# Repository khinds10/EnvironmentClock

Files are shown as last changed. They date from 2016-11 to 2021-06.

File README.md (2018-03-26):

# EnvironmentClock - RPi Time/Weather Clock

#### Flashing RaspberriPi Hard Disk / Install Required Software (Using Ubuntu Linux)

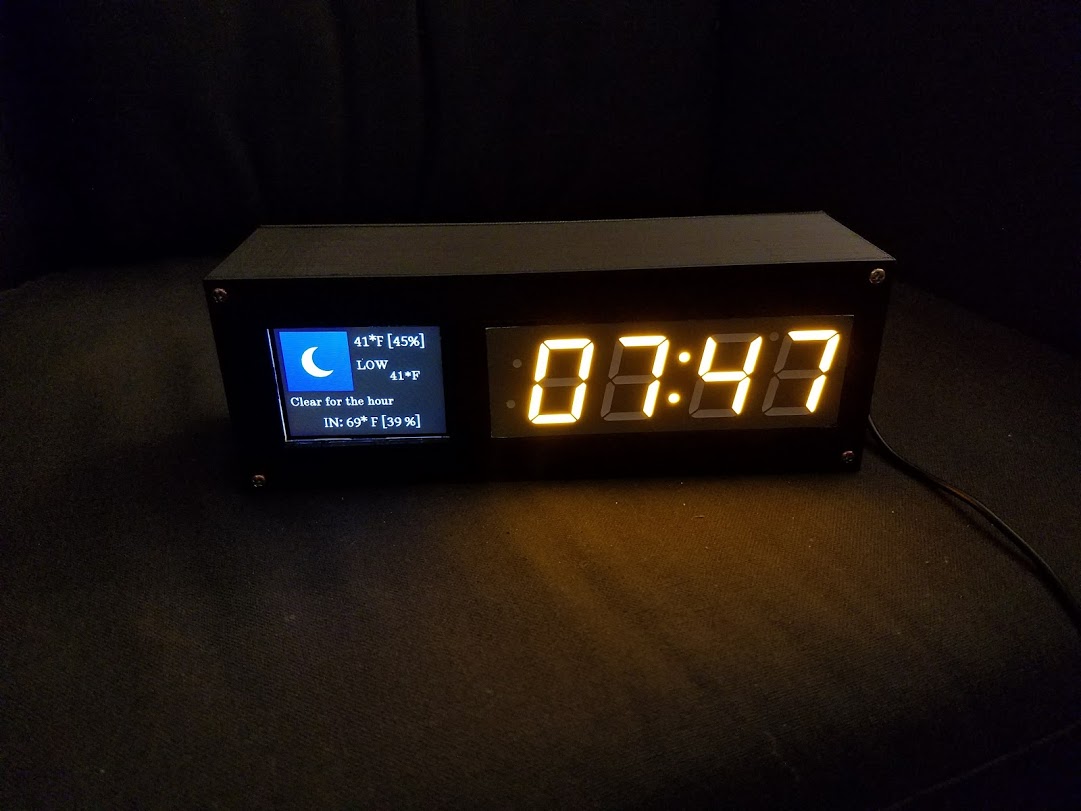
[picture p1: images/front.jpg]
EnvironmentClock


Download "RASPBIAN JESSIE LITE"
https://www.raspberrypi.org/downloads/raspbian/

**Create your new hard disk for DashboardPI**
>Insert the microSD to your computer via USB adapter and create the disk image using the `dd` command
>
> Locate your inserted microSD card via the `df -h` command, unmount it and create the disk image with the disk copy `dd` command
> 
> $ `df -h`
> */dev/sdb1       7.4G   32K  7.4G   1% /media/XXX/1234-5678*
> 
> $ `umount /dev/sdb1`
> 
> **Caution: be sure the command is completely accurate, you can damage other disks with this command**
> 
> *if=location of RASPBIAN JESSIE LITE image file*
> *of=location of your microSD card*
> 
> $ `sudo dd bs=4M if=/path/to/raspbian-jessie-lite.img of=/dev/sdb`
> *(note: in this case, it's /dev/sdb, /dev/sdb1 was an existing factory partition on the microSD)*

**Setting up your RaspberriPi**

*Insert your new microSD card to the raspberrypi and power it on with a monitor connected to the HDMI port*

Login
> user: **pi**
> pass: **raspberry**

Change your account password for security
>`sudo passwd pi`

Enable RaspberriPi Advanced Options
>`sudo raspi-config`

Choose:
`1 Expand File System`

`9 Advanced Options`
>`A2 Hostname`
>*change it to "EnvironmentClock"*
>
>`A4 SSH`
>*Enable SSH Server*
>
>`A7 I2C`
>*Enable i2c interface*

**Enable the English/US Keyboard**

>`sudo nano /etc/default/keyboard`

> Change the following line:
>`XKBLAYOUT="us"`

**Reboot PI for Keyboard layout changes / file system resizing to take effect**
>$ `sudo shutdown -r now`

**Auto-Connect to your WiFi**

>`sudo nano /etc/wpa_supplicant/wpa_supplicant.conf`

Add the following lines to have your raspberrypi automatically connect to your home WiFi
*(if your wireless network is named "linksys" for example, in the following example)*

	network={
	   ssid="linksys"
	   psk="WIRELESS PASSWORD HERE"
	}

**Reboot PI to connect to WiFi network**

>$ `sudo shutdown -r now`
>
>Now that your PI is finally on the local network, you can login remotely to it via SSH.
>But first you need to get the IP address it currently has.
>
>$ `ifconfig`
>*Look for "inet addr: 192.168.XXX.XXX" in the following command's output for your PI's IP Address*

**Go to another machine and login to your raspberrypi via ssh**

> $ `ssh pi@192.168.XXX.XXX`

**Start Installing required packages**

>$ `sudo apt-get update`
>
>$ `sudo apt-get upgrade`
>
>$ `sudo apt-get install vim git python-requests python-smbus i2c-tools python-imaging python-smbus build-essential python-dev rpi.gpio python3 python3-pip libi2c-dev`

**Update local timezone settings**

>$ `sudo dpkg-reconfigure tzdata`

> select your timezone using the interface

**Setup the simple directory `l` command [optional]**

>$ `vi ~/.bashrc`
>
>*add the following line:*
>
>$ `alias l='ls -lh'`
>
>$ `source ~/.bashrc`

**Fix VIM default syntax highlighting [optional]**

>$ `sudo vi /etc/vim/vimrc`
>
>uncomment the following line:
>
>_syntax on_

**Clone Clock repository**

>$ `cd ~`
>
>$ `git clone https://github.com/khinds10/EnvironmentClock.git`

**Install i2c Backpack Python Drivers**

>$ `cd ~`
>
>$ `git clone https://github.com/adafruit/Adafruit_Python_LED_Backpack`
>
>$ `cd Adafruit_Python_LED_Backpack/`
>
>$ `sudo python setup.py install`
>

**DHT11 Install**

>$ `cd ~`
>
>$ `git clone https://github.com/adafruit/Adafruit_Python_DHT.git`
>
>$ `cd Adafruit_Python_DHT/`
>
>$ `sudo python setup.py install`
>
>$ `sudo python ez_setup.py`
>
>$ `cd examples/`
>
>$ `vi simpletest.py`
>

Change the following line:
> sensor = Adafruit_DHT.DHT11

Comment the line out
> pin = 'P8_11'

Uncomment the line and change the pin number to 16
> pin = 16

Run the test

`python simpletest.py`

> You should see a metric reading of Temp and Humidity displayed on the command line.

## Supplies Needed

**1.2 inch LED Display**

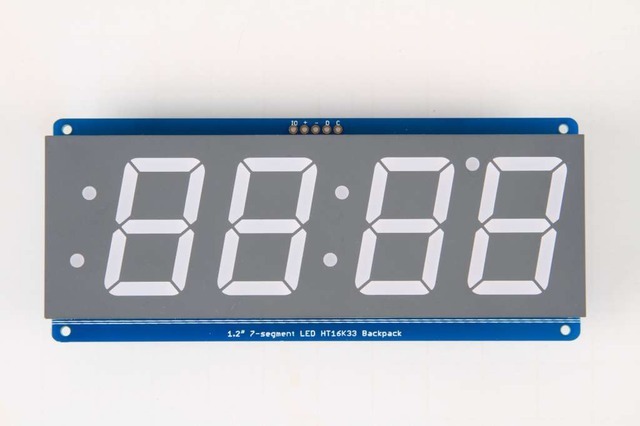
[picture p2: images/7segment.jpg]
1.2 inch LED Display


**DHT11 Humidistat**

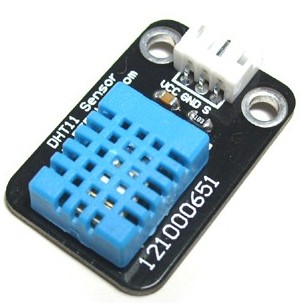
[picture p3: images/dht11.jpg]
DHT11 Humidistat


**2.6" Digole Display**

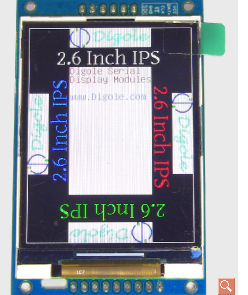
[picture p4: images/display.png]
Digole Display


**RaspberriPi Zero (or Regular RaspberriPi should work)**

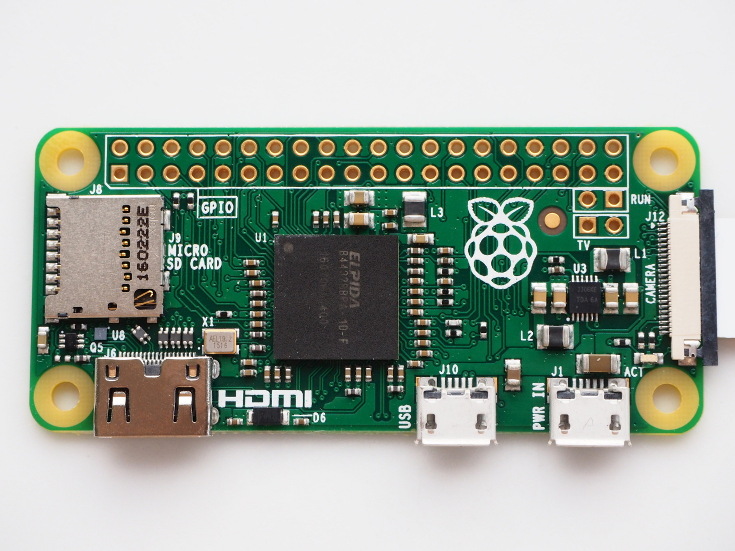
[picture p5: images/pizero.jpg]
Pi Zero


## Build and wire the device

**1) Prepare the Digole Display for i2C**

On the back of the Digole Display, solder the jumper to assign the display to use the i2c protocol
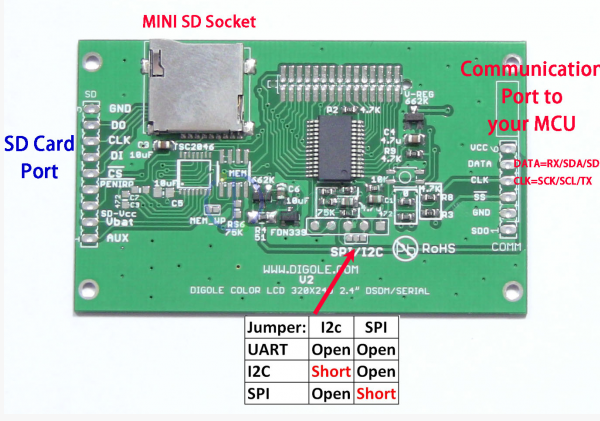
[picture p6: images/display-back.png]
i2c Jumper Digole


**2) Print the Project Enclosure**

Using a 3D printer print the enclosure files included in the 'enclosure/' folder.
.x3g files are MakerBot compatible.  You can also use the .stl and .blend (Blender Program) files to edit and create your own improvements to the design.

**3) Using 4 screws drill and attach the front panel (with the 2 holes) to the 4 sided body.  Then fit the displays in each of the holes.**

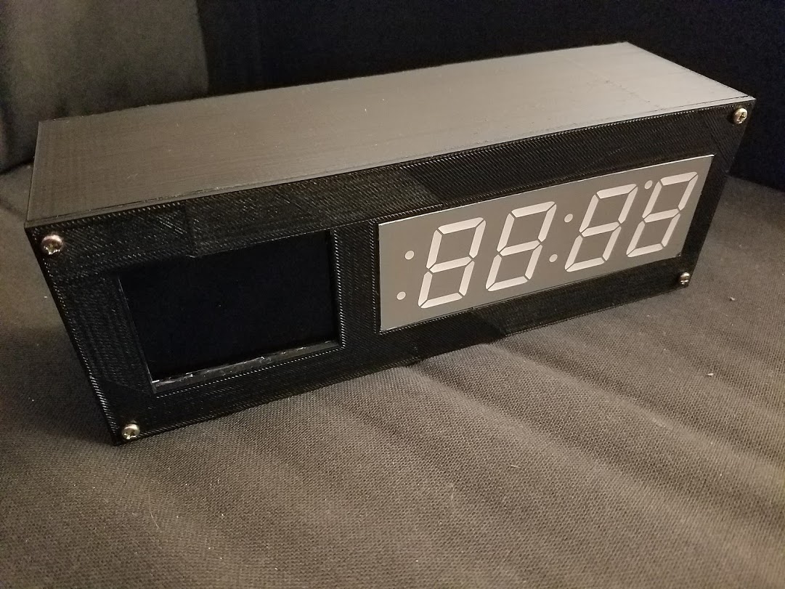
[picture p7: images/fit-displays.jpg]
Fit Displays


**4) Attach the 7 segment and Digole Display using hot glue gun to hold them in place.**

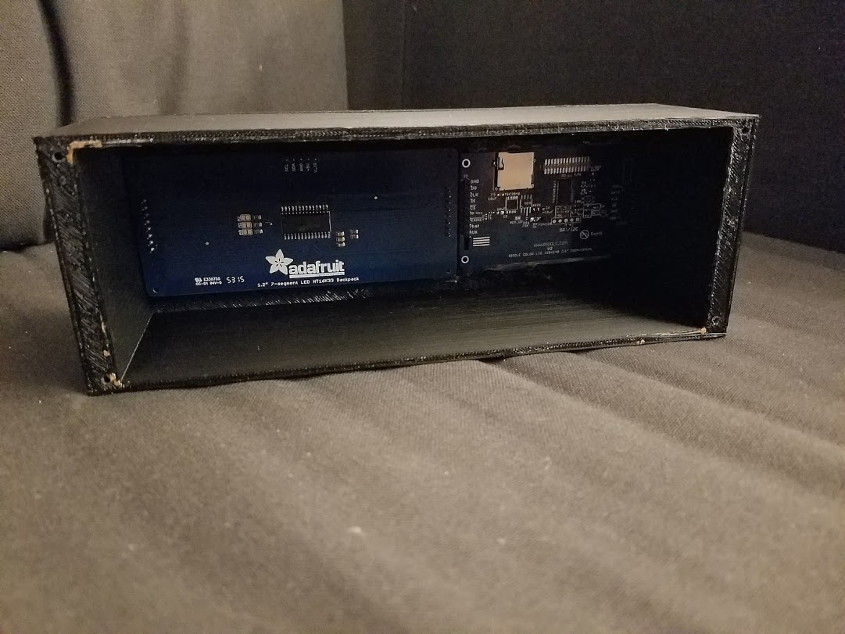
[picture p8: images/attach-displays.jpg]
Hot Glue Displays


**5) Prepare the wires for connection. I use standard jumping wires and a wire cutter to strip the wire bare in the middle of the wires so I can have a bunch connected together glued with a hot glue gun.  (In the image below is my grouped together 5V / GND / SCA / and SCL wires.)**

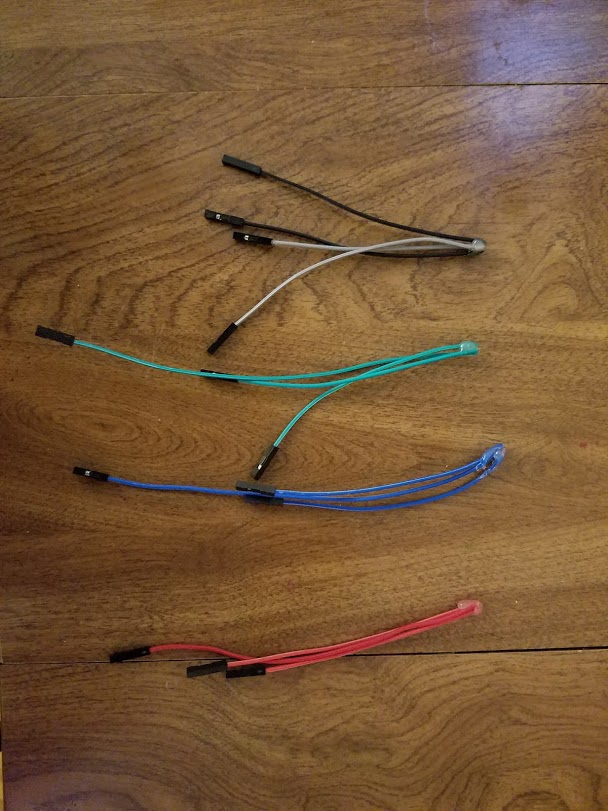
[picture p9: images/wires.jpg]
Grouped Wires


**6) Begin wiring the unit using the wiring diagram below as a guide.**

**The 7 Segment display**

> D -> SDA
>
> C -> SCL
>
> \+ -> 5v
>
> GND -> GND
>
> IO -> 5v
    
**Digole Display**

> GND -> GND
>
> DATA -> SDA
>
> CLK -> SCL
>
> VCC -> 3V
    
**DHT11 Humidistat**

> VCC -> 5V
>
> GND -> GND
>
> DATA -> GPIO 16 / PIN 36
>
    
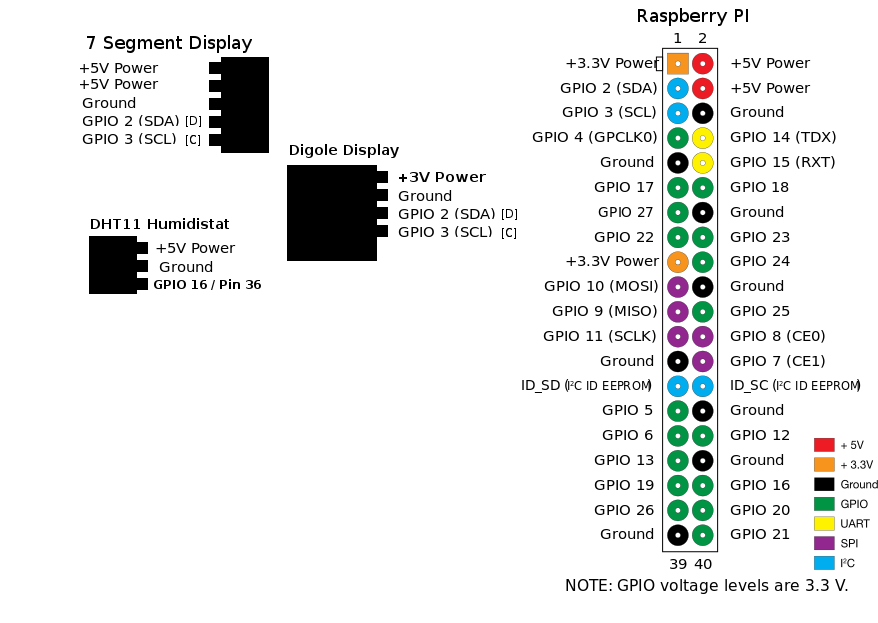
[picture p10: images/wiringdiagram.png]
Wiring Diagram


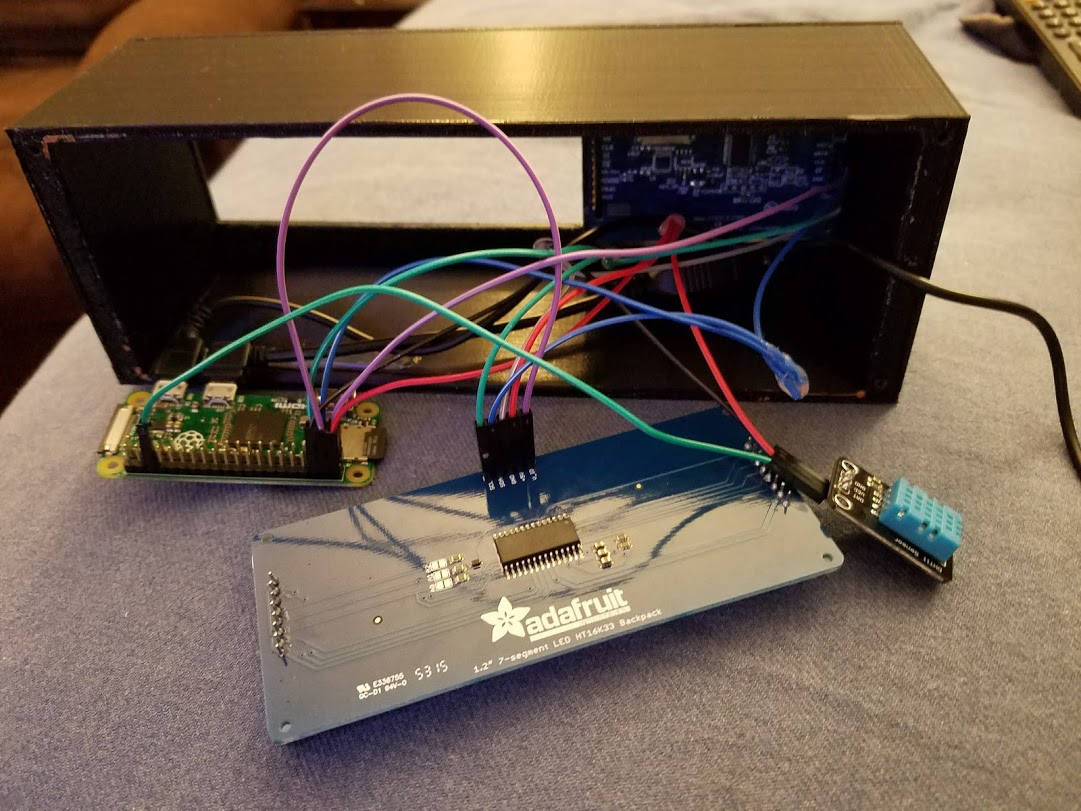
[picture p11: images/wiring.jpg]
Wiring Displays


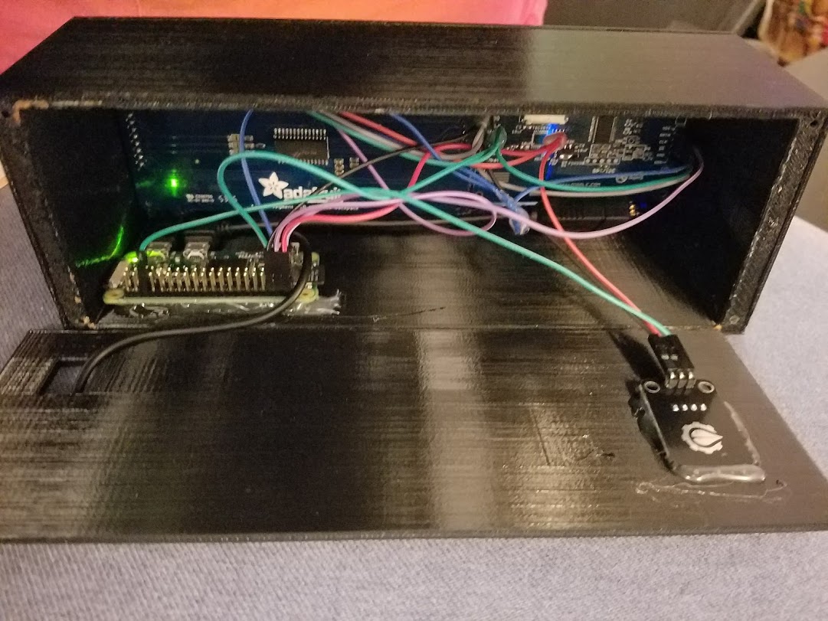
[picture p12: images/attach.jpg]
Attach Wired Displays


**7) Glue the humidistat to the back panel, and run a USB cable through the other back panel hole to power the unit.  Attach the back with only 2 screws in case you need to disassemble for repair.**

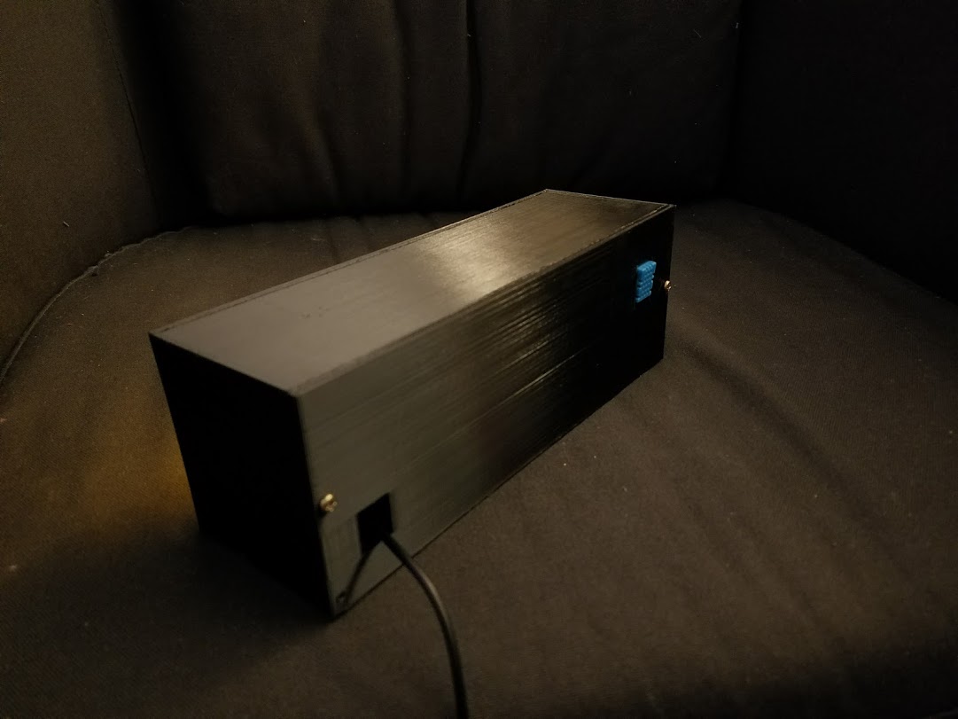
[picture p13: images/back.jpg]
Attach Back Panel


## Configure Application to run correctly in settings.py config file

Find the file `settings.py` and adjust to your current settings

> \# forecast.io API key for local weather information
>
> weatherAPIURL = 'https://api.forecast.io/forecast/'
>
> weatherAPIKey = 'YOUR API KEY FOR FORECAST.IO'
> 
> \# optional for running the remote temp/humidity logger
>
> deviceLoggerAPI = 'mydevicelogger.com'
>
> \# search google to get the Latitude/Longitude for your home location
>
> latitude = 41.4552578
>
> longitude = -72.1665444
>

## Setup Startup Scripts

>$ `crontab -e`

Add the following lines:

`@reboot nohup python /home/pi/EnvironmentClock/clock.py >/dev/null 2>&1`

`@reboot nohup python /home/pi/EnvironmentClock/display.py >/dev/null 2>&1`

Verify the display starts working on reboot

>$ `sudo reboot`

## OPTIONAL: Temp Logger to API script each 10 minutes

>$ `crontab -e`

Add the following lines:

`*/10 * * * * python /home/pi/EnvironmentClock/temp-check.py`

## OPTIONAL: Creating your own weather images to render on the display

Upload your own 128x128 file to the following URL:

http://www.digole.com/tools/PicturetoC_Hex_converter.php 

Choose your image file to upload, add what size you want it to be on the screen (Width/Height)

Select "256 Color for Color OLED/LCD(1 byte/pixel)" in the "Used for" dropdown

Obtain the hex output.

Add the hex output to a display/build/ header (.h) file, use the other ones as guides for syntax.

Include the new file in the digole.c file 
`#include "myimage.h`

Include a new command line hook to your image file in the.
_Note: the command below is saying draw your image at position 10 pixels over 10  pixels down. You can change it to different X,Y coordinates, you can also change the values 128,128 to whatever size your new image actually is._

`} else if (strcmp(digoleCommand, "myimage") == 0) {`
    `drawBitmap256(10, 10, 128, 128, &myimageVariableHere,0);  // myimageVariableHere is defined in your (.h) file`
`}`

Now rebuild (ignore the errors) below to have your new image render with the following command.
>$ `./digole myimage`

**Re-Building [Included] Digole Display Driver for your optional changes**

>$ `cd display/build`

>$ `gcc digole.c`

>$ `mv a.out ../../digole`

>$ `chmod +x ../../digole`

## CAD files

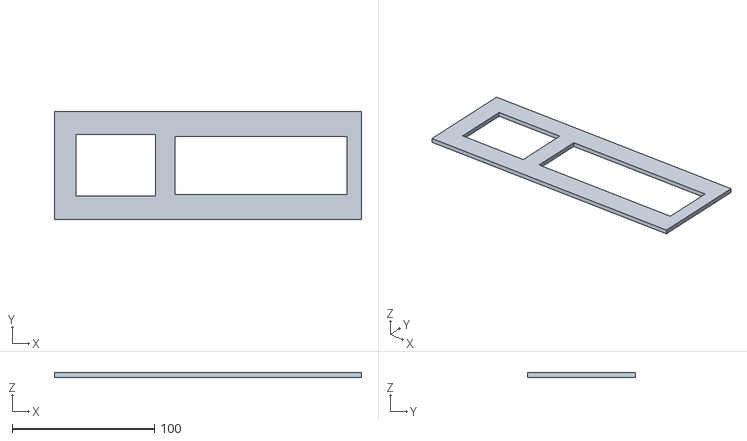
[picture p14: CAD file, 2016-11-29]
enclosure/EnvironmentClock-Lid.stl
215.9 x 76.2 x 3.18

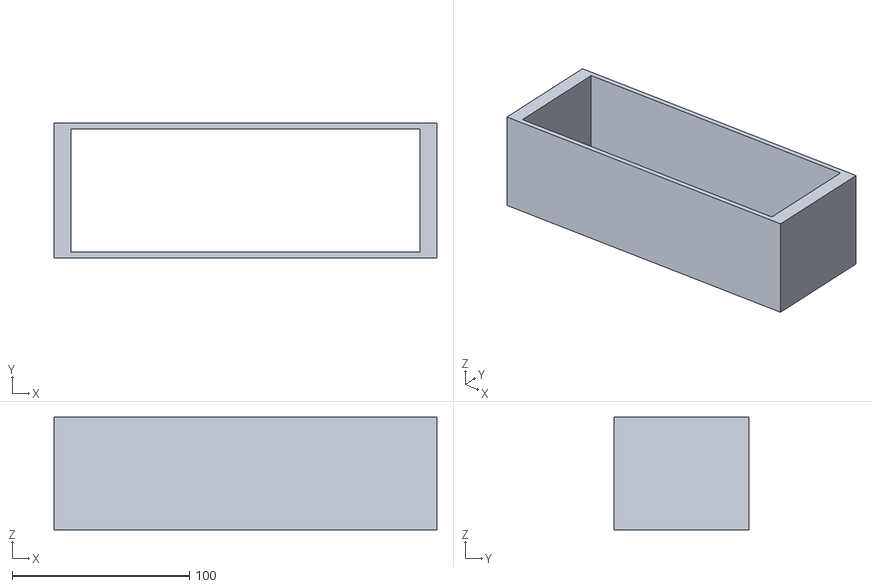
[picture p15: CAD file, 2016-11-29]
enclosure/EnvironmentClock-Box.stl
215.9 x 76.2 x 63.5

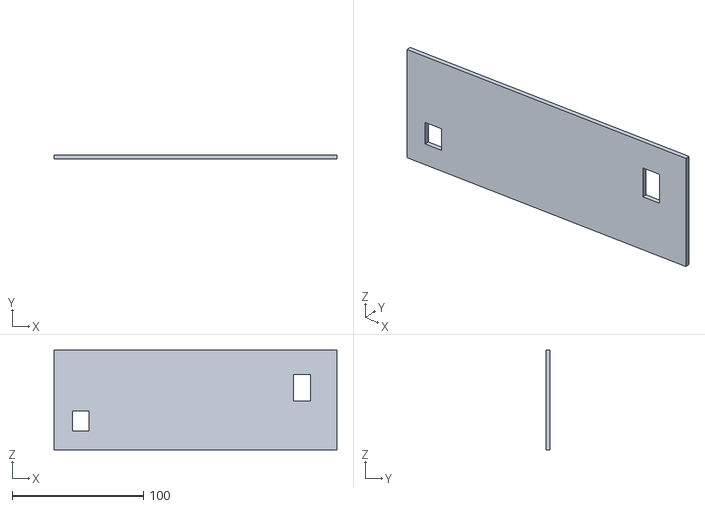
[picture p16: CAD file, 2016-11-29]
enclosure/EnvironmentClock-Back.stl
215.9 x 3.18 x 76.2

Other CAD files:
enclosure/EnvironmentClock-Back.blend
enclosure/EnvironmentClock-Box.blend
enclosure/EnvironmentClock-Lid-scratch.blend
enclosure/EnvironmentClock-Lid.blend

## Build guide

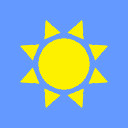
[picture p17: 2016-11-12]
display/build/images/clear-day.jpg

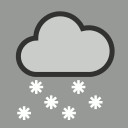
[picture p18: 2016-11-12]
display/build/images/snow.jpg

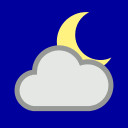
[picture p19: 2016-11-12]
display/build/images/partly-cloudy-night.jpg

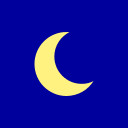
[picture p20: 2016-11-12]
display/build/images/clear-night.jpg

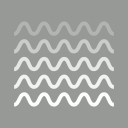
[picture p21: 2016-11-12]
display/build/images/fog.jpg

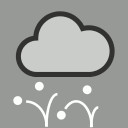
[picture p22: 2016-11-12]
display/build/images/sleet.jpg

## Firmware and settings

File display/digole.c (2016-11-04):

/////////////////////////////////
// Digole Digital
/////////////////////////////////
#include <arpa/inet.h>
#include <dirent.h>
#include <errno.h>
#include <net/if.h>
#include <netinet/in.h>
#include <netinet/in.h>
#include <pthread.h>
#include <stdint.h>
#include <stdio.h>
#include <stdlib.h>
#include <string.h>
#include <stropts.h>
#include <sys/ioctl.h>
#include <sys/socket.h>
#include <sys/types.h>
#include <sys/time.h>
#include <time.h>
#include <unistd.h>
#include <inttypes.h>
#include <linux/i2c-dev.h>
#include <fcntl.h>
#include <sys/ioctl.h>
#include <sys/stat.h>

#define _TEXT_ 0
#define _GRAPH_ 1
#define _rs 0
#define _rst 2
#define LCDWIDTH 128
#define LCDHEIGHT 64

// an abs() :)
#define abs(a) (((a) < 0) ? -(a) : (a))

// bit set
#define _BV(bit) (0x1 << (bit))
#define swap(a, b) { uint8_t t = a; a = b; b = t; }

int fd,fd2;
const unsigned char fonts[] = {6, 10, 18, 51, 120, 123};

// name of the port we will be using, Rasberry Pi model B (i2c-1)
char *fileName = "/dev/i2c-1";

// address of I2C device Digole
int  address = 0x27;

void delay (unsigned int howLong){
  struct timespec sleeper, dummy ;
  sleeper.tv_sec  = (time_t)(howLong / 1000) ;
  sleeper.tv_nsec = (long)(howLong % 1000) * 1000000 ;
  nanosleep (&sleeper, &dummy) ;
}
 int writebyte (uint8_t command) {
	    if( i2c_smbus_write_byte( fd, command ) < 0 ) {
            printf(" Error writing to i2c slave ");
			return -1;
        }
		return 0;
 }
 int writecmd(char *command) {
		char tmp[1000];
		int i;
		sprintf(tmp,"%s",command);
        printf(" Digole CMD: %s ",command);
		for (i=0;i<strlen(tmp);i++) {
			printf("%c",tmp[i]);
		    if ((writebyte(tmp[i]))==-1) {
				printf(" Error writing to i2c slave ");
				return -1;
			}
		}
		return 0;
 }
void setRot90(void) {
    writecmd("SD1");
}
void setRot180(void) {
    writecmd("SD2");
}
void setRot270(void) {
    writecmd("SD3");
}
void undoRotation(void) {
    writecmd("SD0");
}
void setRotation(uint8_t d) {
    writecmd("SD");
    writebyte(d);
}
void setContrast(uint8_t c) {
    writecmd("CT");
    writebyte(c);
}
int print(char *command) {
    char tmp[1000];
    writecmd("TT");
    writecmd(command);
    writebyte(0);
    return 0;
}
void displayStartScreen(uint8_t c) {
    writecmd("DSS");
    writebyte(c);
}
void drawBox(uint8_t x, uint8_t y, uint8_t w, uint8_t h) {
    writecmd("FR");
    writebyte(x);
    writebyte(y);
    writebyte(x + w);
    writebyte(y + h);
}
void drawFrame(uint8_t x, uint8_t y, uint8_t w, uint8_t h) {
    writecmd("DR");
    writebyte(x);
    writebyte(y);
    writebyte(x + w);
    writebyte(y + h);
}
void setColor(uint8_t color) {
    writecmd("SC");
    writebyte(color);
}
void drawBoxfill(uint8_t x, uint8_t y, uint8_t w, uint8_t h) {
	setColor(0);
	drawBox(x, y, w,h);
	setColor(1);
	drawFrame(x, y, w,h);
}
void clearobd() {
	setColor(0);
	drawBox(0, 0, 128,57);
	setColor(1);
}
void drawCircle(uint8_t x, uint8_t y, uint8_t r, uint8_t f) {
    writecmd("CC");
    writebyte(x);
    writebyte(y);
    writebyte(r);
    writebyte(f);
}
void drawDisc(uint8_t x, uint8_t y, uint8_t r) {
    drawCircle(x, y, r, 1);
}
void drawPixel(uint8_t x, uint8_t y, uint8_t color) {
    writecmd("DP");
    writebyte(x);
    writebyte(y);
    writebyte(color);
}
void drawLine(uint8_t x, uint8_t y, uint8_t x1, uint8_t y1) {
    writecmd("LN");
    writebyte(x);
    writebyte(y);
    writebyte(x1);
    writebyte(y1);
}
void drawLineTo(uint8_t x, uint8_t y) {
    writecmd("LT");
    writebyte(x);
    writebyte(y);
}
void drawHLine(uint8_t x, uint8_t y, uint8_t w) {
    drawLine(x, y, x + w, y);
}
void drawVLine(uint8_t x, uint8_t y, uint8_t h) {
    drawLine(x, y, x, y + h);
}
void nextTextLine(void) {
    writebyte((uint8_t) 0);
    writecmd("TRT");
}
void setFont(uint8_t font) {
    writecmd("SF");
    writebyte(font);
}
void directCommand(uint8_t d) {
    writecmd("MCD");
    writebyte(d);
}
void directData(uint8_t d) {
    writecmd("MDT");
    writebyte(d);
}
void moveArea(uint8_t x0, uint8_t y0, uint8_t x1, uint8_t y1, char xoffset, char yoffset) {
    writecmd("MA");
    writebyte(x0);
    writebyte(y0);
    writebyte(x1);
    writebyte(y1);
    writebyte(xoffset);
    writebyte(yoffset);
}
void uploadStartScreen(int lon,  uint8_t *data,int xdelay) {
     int j,y;
     uint8_t c;
    writecmd("SSS");
    writebyte((uint8_t) (lon % 256));
    writebyte((uint8_t) (lon / 256));
    for (j = 0; j < lon;j++) {
        delay(xdelay);
        c=*(data+j);
        writebyte(c);
		printf(" 0x%.2X ",c);
		if ((j%16)==0) printf(" ");
    }
}
void uploadUserFont(int lon, uint8_t *data, uint8_t sect) {
     uint8_t c;
	 int j;
    writecmd("SUF");
    writebyte(sect);
    writebyte((uint8_t) (lon % 256));
    writebyte((uint8_t) (lon / 256));
    for ( j = 0; j < lon; j++) {
        if((j%32)==0) delay(10);
        delay(2);
        c=*(data+j);
        writebyte(c);
    }
}
void clearScreen(void) {
        writebyte('C');
		writebyte('L');
		writebyte(0);
		writebyte('C');
		writebyte('L');
		writebyte(0);
}
//set display mode
void setMode(uint8_t m) {
        writecmd("DM");
        writebyte(m);
}
//set text position back to previous, only one back allowed
void setTextPosBack(void) {
	writecmd("ETB");
}
void setTextPosOffset(char xoffset, char yoffset) {
	writecmd("ETO");
	writebyte(xoffset);
	writebyte(yoffset);
}
void setTextPosAbs(uint8_t x, uint8_t y) {
	writecmd("ETP");
	writebyte(x);
	writebyte(y);
}
void setLinePattern(uint8_t pattern) {
	writecmd("SLP");
	writebyte(pattern);
 }
void setPrintPos(uint8_t x, uint8_t y, uint8_t graph ) {
        if (graph == _TEXT_)
            writecmd("TP");
		else
            writecmd("GP");
         writebyte(x);
         writebyte(y);
}
void disableCursor(void) {
    writecmd("CS0");
}
void enableCursor(void) {
    writecmd("CS1");
}
void drawStr(uint8_t x, uint8_t y, char *s) {
		setTextPosOffset(x,y);
		print(s);
}
/*----------Functions for Graphic LCD/OLED adapters only---------*/
void drawBitmap(uint8_t x, uint8_t y, uint8_t w, uint8_t h, const uint8_t *bitmap) {
    uint8_t i = 0;
	int j;
    if ((w & 7) != 0)
        i = 1;
    writecmd("DIM");
    writebyte(x); //x;
    writebyte(y);
    writebyte(w);
    writebyte(h);
    for ( j = 0; j < h * ((w >> 3) + i); j++) {
        writebyte(*(bitmap + j));
    }
}
void drawBitmapc(uint8_t x, uint8_t y, uint8_t w, uint8_t h, const uint8_t *bitmap,uint8_t c ) {
    uint8_t i = 0;
	int j;
	if (c!=0) c=0xff;
    if ((w & 7) != 0)
        i = 1;
    writecmd("DIM");
    writebyte(x);
    writebyte(y);
    writebyte(w);
    writebyte(h);
    for ( j = 0; j < h * ((w >> 3) + i); j++) {
        writebyte((*(bitmap + j))^c);
    }
}
const char *byte_to_binary(int x) {
    static char b[9];
    b[0] = '\0';
    int z;
    for (z = 128; z > 0; z >>= 1){
        strcat(b, ((x & z) == z) ? "1" : "0");
    }
    return b;
}
 int printxy(uint8_t x, uint8_t y, char *command) {
	setPrintPos(x, y,_TEXT_);
	writecmd("TT");
	writecmd(command);
	writebyte(0);
	return 0;
 }
 int printxy_abs(uint8_t x, uint8_t y, char *command) {
	setTextPosAbs(x, y);
	writecmd("TT");
	writecmd(command);
	writebyte(0);
	return 0;
 }
 int printxyf_abs(uint8_t x, uint8_t y,uint8_t font, char *command) {
	setFont(fonts[font]);
	setTextPosAbs(x, y);
	writecmd("TT");
	writecmd(command);
	writebyte(0);
	return 0;
 }
int printxyf(uint8_t x, uint8_t y,uint8_t font, char *command) {
	setFont(fonts[font]);
	setPrintPos(x, y,_TEXT_);
	writecmd("TT");
	writecmd(command);
	writebyte(0);
	return 0;
 }
int printnxyf(uint8_t x, uint8_t y,uint8_t font, int command) {
    char tmp[100];
    sprintf(tmp,"%d",command);
    setFont(fonts[font]);
    setPrintPos(x, y,_TEXT_);
    writecmd("TT");
    writecmd(tmp);
    writebyte(0);
    return 0;
 }
 int printnxyf_abs(uint8_t x, uint8_t y,uint8_t font, int command) {
    char tmp[100];
    sprintf(tmp,"%d",command);
    setFont(fonts[font]);
    setTextPosAbs(x, y);
    writecmd("TT");
    writecmd(tmp);
    writebyte(0);
    return 0;
 }
int LCDInit( uint8_t contrast) {
    // Open port for reading and writing
    if ((fd = open (fileName, O_RDWR)) < 0) {
        printf(" Failed to open i2c port ");
        return -1;
    }
    // Set the port options and set the address of the device
    if (ioctl(fd, I2C_SLAVE, address) < 0) {
        printf(" Unable to get bus access to talk to slave ");
        return -1;
    }
	return (0);
}
void LCDdrawbitmap(uint8_t x, uint8_t y, uint8_t *bitmap, uint8_t w, uint8_t h,uint8_t color,uint8_t *dest) {
uint8_t j,i,jj;
uint8_t o,p,k;
printf(" 000 0b ");
k=0;
for (p=0;p<(w/8);p++)
  for (o=0;o<=7;o++) {
		for ( j=0; j<h; j++) {
			for ( i=0; i<(w/8); i++ ) {
				uint8_t d = *(bitmap + i + (j)*w/8);
				for (jj = 8; jj>0; jj--)	{
					if (((jj-1)==(7-o)) && (i==p)) {
						if (d & _BV(jj-1))
						  printf("1");
						else
						  printf("0");
						k++;
						if (k%8==0)
							printf(",0b");
					 }
				}
			}
		}
		k=0;
		printf(" %.03d 0b ",(p*8)+o);
	}
}

int main (int argc, char* argv[]) {
    int i=0;
	LCDInit(0);
    printf(" %s ", argv[0]);

    // show incoming commands   
    printf(" arg%d=%s ", 1, argv[1]);
    printf(" arg%d=%s ", 2, argv[2]);

    // parse command to char
    char digoleCommand[100];
    sprintf(digoleCommand,"%s",argv[1]);
    
    // based on command issue call to Digole screen
    if (strcmp(digoleCommand, "setRot90") == 0) {
        setRot90();
    } else if (strcmp(digoleCommand, "setRot180") == 0) {
        setRot180();
    } else if (strcmp(digoleCommand, "setRot270") == 0) {
        setRot270();
    } else if (strcmp(digoleCommand, "undoRotation") == 0) {
        undoRotation();
    } else if (strcmp(digoleCommand, "setRotation") == 0) {
        setRotation((uint8_t)atoi(argv[2]));
    } else if (strcmp(digoleCommand, "setContrast") == 0) {
        setContrast((uint8_t)atoi(argv[2]));
    } else if (strcmp(digoleCommand, "displayStartScreen") == 0) {
        displayStartScreen((uint8_t)atoi(argv[2]));
    } else if (strcmp(digoleCommand, "drawBox") == 0) {
        drawBox((uint8_t)atoi(argv[2]), (uint8_t)atoi(argv[3]), (uint8_t)atoi(argv[4]), (uint8_t)atoi(argv[5]));
    } else if (strcmp(digoleCommand, "drawFrame") == 0) {
        drawFrame((uint8_t)atoi(argv[2]), (uint8_t)atoi(argv[3]), (uint8_t)atoi(argv[4]), (uint8_t)atoi(argv[5]));
    } else if (strcmp(digoleCommand, "setColor") == 0) {
        setColor((uint8_t)atoi(argv[2]));
    } else if (strcmp(digoleCommand, "drawBoxfill") == 0) {
        drawBoxfill((uint8_t)atoi(argv[2]), (uint8_t)atoi(argv[3]), (uint8_t)atoi(argv[4]), (uint8_t)atoi(argv[5]));
    } else if (strcmp(digoleCommand, "clearobd") == 0) {
        clearobd();
    } else if (strcmp(digoleCommand, "drawCircle") == 0) {
        drawCircle((uint8_t)atoi(argv[2]), (uint8_t)atoi(argv[3]), (uint8_t)atoi(argv[4]), (uint8_t)atoi(argv[5]));
    } else if (strcmp(digoleCommand, "drawDisc") == 0) {
        drawDisc((uint8_t)atoi(argv[2]), (uint8_t)atoi(argv[3]), (uint8_t)atoi(argv[4]));
    } else if (strcmp(digoleCommand, "drawPixel") == 0) {
        drawPixel((uint8_t)atoi(argv[2]), (uint8_t)atoi(argv[3]), (uint8_t)atoi(argv[4]));
    } else if (strcmp(digoleCommand, "drawLine") == 0) {
        drawLine((uint8_t)atoi(argv[2]), (uint8_t)atoi(argv[3]), (uint8_t)atoi(argv[4]), (uint8_t)atoi(argv[5]));
    } else if (strcmp(digoleCommand, "drawLineTo") == 0) {
        drawLineTo((uint8_t)atoi(argv[2]), (uint8_t)atoi(argv[3]));
    } else if (strcmp(digoleCommand, "drawHLine") == 0) {
        drawHLine((uint8_t)atoi(argv[2]), (uint8_t)atoi(argv[3]), (uint8_t)atoi(argv[4]));
    } else if (strcmp(digoleCommand, "drawVLine") == 0) {
        drawVLine((uint8_t)atoi(argv[2]), (uint8_t)atoi(argv[3]), (uint8_t)atoi(argv[4]));
    } else if (strcmp(digoleCommand, "nextTextLine") == 0) {
        nextTextLine();
    } else if (strcmp(digoleCommand, "setFont") == 0) {
        setFont((uint8_t)atoi(argv[2]));
    } else if (strcmp(digoleCommand, "directCommand") == 0) {
        directCommand((uint8_t)atoi(argv[2]));
    } else if (strcmp(digoleCommand, "directData") == 0) {
        directData((uint8_t)atoi(argv[2]));
    } else if (strcmp(digoleCommand, "moveArea") == 0) {
        moveArea((uint8_t)atoi(argv[2]), (uint8_t)atoi(argv[3]), (uint8_t)atoi(argv[4]), (uint8_t)atoi(argv[5]), (uint8_t)atoi(argv[6]), (uint8_t)atoi(argv[7]));
    } else if (strcmp(digoleCommand, "uploadStartScreen") == 0) {
        //uploadStartScreen(int lon,  uint8_t *data,int xdelay);
    } else if (strcmp(digoleCommand, "uploadUserFont") == 0) {
        //uploadUserFont(int lon, uint8_t *data, uint8_t sect);
    } else if (strcmp(digoleCommand, "clear") == 0) {
        clearScreen();
    } else if (strcmp(digoleCommand, "setMode") == 0) {
        setMode((uint8_t)atoi(argv[2]));
    } else if (strcmp(digoleCommand, "setTextPosBack") == 0) {
        setTextPosBack();
    } else if (strcmp(digoleCommand, "setTextPosOffset") == 0) {
        setTextPosOffset((uint8_t)atoi(argv[2]), (uint8_t)atoi(argv[3]));
    } else if (strcmp(digoleCommand, "setTextPosAbs") == 0) {
        setTextPosAbs((uint8_t)atoi(argv[2]), (uint8_t)atoi(argv[3]));
    } else if (strcmp(digoleCommand, "setLinePattern") == 0) {
        setLinePattern((uint8_t)atoi(argv[2]));
    } else if (strcmp(digoleCommand, "setPrintPos") == 0) {
        setPrintPos((uint8_t)atoi(argv[2]), (uint8_t)atoi(argv[3]), (uint8_t)atoi(argv[4]));
    } else if (strcmp(digoleCommand, "disableCursor") == 0) {
        disableCursor();
    } else if (strcmp(digoleCommand, "enableCursor") == 0) {
        enableCursor();
    } else if (strcmp(digoleCommand, "drawStr") == 0) {
        drawStr((uint8_t)atoi(argv[2]), (uint8_t)atoi(argv[3]), argv[4]);
    } else if (strcmp(digoleCommand, "drawBitmap") == 0) {
        //drawBitmap((uint8_t)atoi(argv[2]), (uint8_t)atoi(argv[3]), (uint8_t)atoi(argv[4]), (uint8_t)atoi(argv[5]), (uint8_t)atoi(argv[2]));
    } else if (strcmp(digoleCommand, "drawBitmapc") == 0) {
        //drawBitmapc((uint8_t)atoi(argv[2]), (uint8_t)atoi(argv[2]), (uint8_t)atoi(argv[2]), (uint8_t)atoi(argv[2]), const uint8_t *bitmap,uint8_t c );
    } else if (strcmp(digoleCommand, "print") == 0) {
        print(argv[2]);
    } else if (strcmp(digoleCommand, "printxy") == 0) {
        printxy((uint8_t)atoi(argv[2]), (uint8_t)atoi(argv[3]), argv[4]);
    } else if (strcmp(digoleCommand, "printxy_abs") == 0) {
        printxy_abs((uint8_t)atoi(argv[2]), (uint8_t)atoi(argv[3]), argv[4]);
    } else if (strcmp(digoleCommand, "printxyf_abs") == 0) {
        printxyf_abs((uint8_t)atoi(argv[2]), (uint8_t)atoi(argv[3]),(uint8_t)atoi(argv[4]), argv[5]) ;
    } else if (strcmp(digoleCommand, "printxyf") == 0) {
        printxyf((uint8_t)atoi(argv[2]), (uint8_t)atoi(argv[3]),(uint8_t)atoi(argv[4]), argv[5]);
    } else if (strcmp(digoleCommand, "printnxyf") == 0) {
        printnxyf((uint8_t)atoi(argv[2]), (uint8_t)atoi(argv[3]),(uint8_t)atoi(argv[4]), (uint8_t)atoi(argv[5]));
    } else if (strcmp(digoleCommand, "printnxyf_abs") == 0) {
        printnxyf_abs((uint8_t)atoi(argv[2]), (uint8_t)atoi(argv[3]),(uint8_t)atoi(argv[4]), (uint8_t)atoi(argv[5]));
    } else if (strcmp(digoleCommand, "LCDdrawbitmap") == 0) {
        //LCDdrawbitmap((uint8_t)atoi(argv[2]), (uint8_t)atoi(argv[3]), (uint8_t)atoi(argv[4]), (uint8_t)atoi(argv[5]), (uint8_t)atoi(argv[6]),(uint8_t)atoi(argv[7]),(uint8_t)argv[8]);
    }
    printf("\n");
	return 0;
}

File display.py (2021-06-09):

#!/usr/bin/python
# Kevin Hinds http://www.kevinhinds.com
# License: GPL 2.0
import datetime as dt
import time, json, string, cgi, subprocess, json
import settings as settings
import Adafruit_DHT

# Raspberry Pi with DHT sensor - connected to GPIO16 / Pin 36
sensor = sensor = Adafruit_DHT.DHT11
pin = 18

def getIcon(openweatherCode):
    """get digole icon name from openweather map icon code"""
    if openweatherCode == '01d':
        return "clear-day"
    elif openweatherCode == '01n':
        return "clear-night"
    elif openweatherCode == '03d':
        return "cloudy"
    elif openweatherCode == '03n':
        return "cloudy"
    elif openweatherCode == '02d':
        return "partly-cloudy-day"
    elif openweatherCode == '04d':
        return "partly-cloudy-day"
    elif openweatherCode == '02n':
        return "partly-cloudy-night"
    elif openweatherCode == '04n':
        return "partly-cloudy-night"
    elif openweatherCode == '50d':
        return "fog"
    elif openweatherCode == '50n':
        return "fog"
    elif openweatherCode == '09d':
        return "rain"
    elif openweatherCode == '09n':
        return "rain"
    elif openweatherCode == '10d':
        return "rain"
    elif openweatherCode == '10n':
        return "rain"
    elif openweatherCode == '11d':
        return "rain"
    elif openweatherCode == '11n':
        return "rain"
    elif openweatherCode == '13d':
        return "snow"
    elif openweatherCode == '13n':
        return "snow" 
    else:
        return "cloudy"

# begin the loop to get the current weather for display
while True:
    try:
        # get current date and time
        date=dt.datetime.now()

        # get 10 readings and average, in case the humidistat is inaccurate
        count, readingCount, avgTemperature, avgHumidity = [ 0, 0, 0, 0 ]
        while (count < 10):    
            humidity, temperature = Adafruit_DHT.read_retry(sensor, pin)
            if humidity is not None and temperature is not None:
                avgTemperature = avgTemperature + temperature
                avgHumidity = avgHumidity + humidity
                readingCount = readingCount + 1                
            count = count + 1
        avgTemperature = avgTemperature / readingCount
        insideTemperature = int(avgTemperature * 9/5 + 32)
        avgHumidity = avgHumidity / readingCount
        insideHumidity = int(avgHumidity)
 
	    # DHT11 adjust for this unit
        insideTemperature = int(insideTemperature) - 4
        insideHumidity = int(avgHumidity)
       
        # get current forecast from location
        weatherInfo = json.loads(subprocess.check_output(['curl', settings.weatherAPIURL]))
        currentConditions = weatherInfo['current']
        apparentTemperature = str(int(currentConditions['feels_like']))
        humidity = str(int(currentConditions['humidity']))
        windSpeed = str(int(currentConditions['wind_speed']))
        cloudCover = str(int(currentConditions['clouds']))
        icon = getIcon(currentConditions['weather'][0]['icon'])
        summary = str(currentConditions['weather'][0]['description'])
        summary = (summary[:27] + '...') if len(summary) > 29 else summary
        summary = summary.title()

        # conditions for the day
        dailyConditions = weatherInfo['daily']
        dailyConditions = dailyConditions[0]
        apparentTemperatureMin = str(int(dailyConditions['temp']['min']))
        apparentTemperatureMax = str(int(dailyConditions['temp']['max']))
        
        # clear and setup display to show basic info
        subprocess.call(["/home/pi/EnvironmentClock/digole", "clear"])
        subprocess.call(["/home/pi/EnvironmentClock/digole", "setRot90"])
        subprocess.call(["/home/pi/EnvironmentClock/digole", icon])
        subprocess.call(["/home/pi/EnvironmentClock/digole", "setFont", "18"])
        subprocess.call(["/home/pi/EnvironmentClock/digole", "setColor", "255"])
        subprocess.call(["/home/pi/EnvironmentClock/digole", "printxy_abs", "10", "178", summary])
        subprocess.call(["/home/pi/EnvironmentClock/digole", "setFont", "51"])
        subprocess.call(["/home/pi/EnvironmentClock/digole", "printxy_abs", "150", "40", date.strftime('%a, %b %d')])
        
        # print the min daily temp in the evening and night, print the day max temp in the morning and daytime
        if dt.datetime.now().hour > 16 or dt.datetime.now().hour < 6:
            subprocess.call(["/home/pi/EnvironmentClock/digole", "setColor", "223"])
            subprocess.call(["/home/pi/EnvironmentClock/digole", "printxy_abs", "150", "130", "LOW\n" + apparentTemperatureMin + '*F'])
        else:
            subprocess.call(["/home/pi/EnvironmentClock/digole", "setColor", "222"])
            subprocess.call(["/home/pi/EnvironmentClock/digole", "printxy_abs", "150", "130", "HIGH\n" + apparentTemperatureMax + '*F'])
        
        # show indoor / outdoor temp
        subprocess.call(["/home/pi/EnvironmentClock/digole", "setFont", "120"])
        
        subprocess.call(["/home/pi/EnvironmentClock/digole", "setColor", "255"])
        subprocess.call(["/home/pi/EnvironmentClock/digole", "printxy_abs", "150", "85", apparentTemperature + "*F [" + humidity + "%]"])
        
        subprocess.call(["/home/pi/EnvironmentClock/digole", "setColor", "250"])
        subprocess.call(["/home/pi/EnvironmentClock/digole", "printxy_abs", "70", "230", "IN: " + str(insideTemperature) + "* F [" + str(insideHumidity) + " %]"])

        # wait 5 minutes
        time.sleep(300)

    except (Exception):
        # Network or other issue, wait 5 minutes
        time.sleep(300)

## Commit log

2016-11-04 added digole display driver with c library and screenshot of commands
2016-11-10 added digole drivers for showing forcast icons as images
2016-11-12 added clock i2c script and setup instructions
2016-11-12 add the display python controller for the temp and weather, fixed typo in rain.h variable name
    [display.py]
2016-11-29 added construction images / 3D printer files and updated scripts
    [EnvironmentClock-Back.blend, EnvironmentClock-Back.stl, EnvironmentClock-Box.blend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]
2016-11-30 wiring diagram image and begin readme build instructions
2016-11-30 fix for live on the unit
    [clock.py, display.py]
2016-12-06 must have full path for the digole display driver
2017-04-21 fix the weather api URL to have the params for forecast.io
    [temp-check.py]
